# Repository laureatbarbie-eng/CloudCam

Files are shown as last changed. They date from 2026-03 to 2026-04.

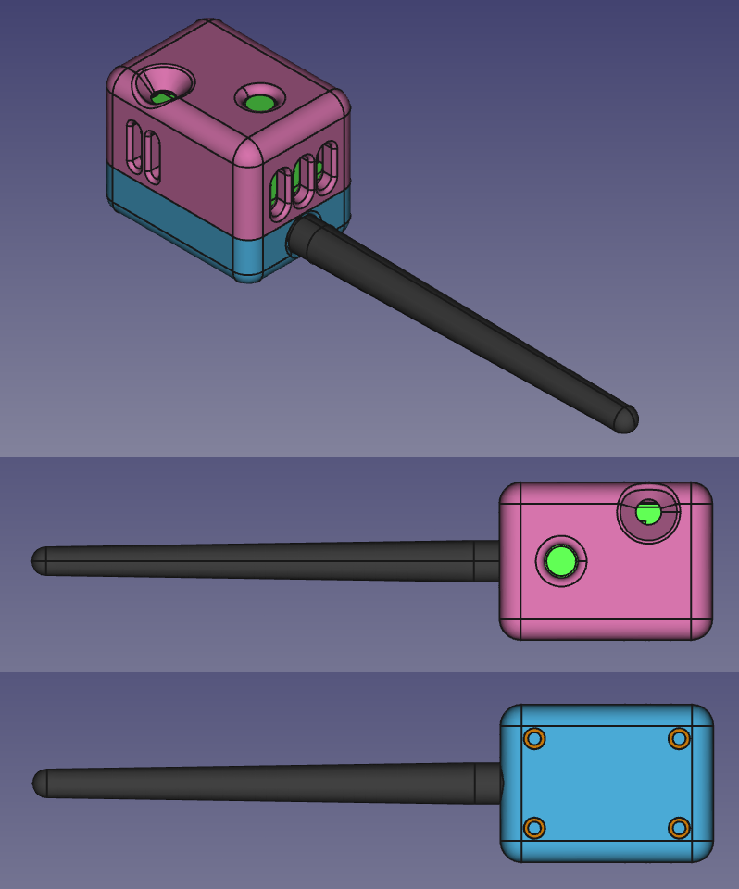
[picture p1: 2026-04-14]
esp-32cam case/cam_multiview_cad.png

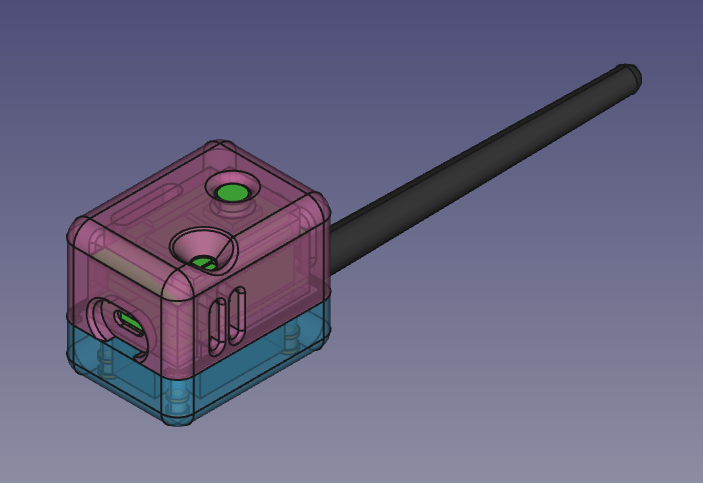
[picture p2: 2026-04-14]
esp-32cam case/cam-transparent-cad.png

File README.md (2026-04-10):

# Проект Скайр (Skyr): Моностатический измеритель ВНГО (CloudCam)

Аппаратно-программный комплекс для пассивного оптического измерения высоты нижней границы облачности (ВНГО), скорости и направления ее движения, а также общего балла облачности. 

Система разработана на основе моностатического метода С.В. Зуева и использует две камеры, расположенные вплотную (на малом базисе), но оснащенные объективами с разными фокусными расстояниями (например, с углами обзора 120° и 160°). За счет разницы в масштабе и использования стереоскопических алгоритмов система вычисляет расстояние до облачного фрагмента, а оптический поток позволяет определить параметры ветра.

---

## 1. Требования к оборудованию

Для сборки комплекса вам потребуются:
*   **Вычислительный модуль:** Raspberry Pi 5 (или 4) с установленной Raspberry Pi OS.
*   **Камеры:** 2× модуля ESP32-CAM (рекомендуются сенсоры OV2640 или OV5640) со сверхширокоугольными линзами (120° — `cam120` и 160° — `cam160`).
*   **Питание:** Стабильный источник 5V (рекомендуется DC-DC преобразователь), общая "земля" (GND).
*   **Дополнительно:** USB-TTL программатор (3.3V) для прошивки ESP32-CAM, калибровочный шаблон (шахматная доска 9x6).
*   **Монтаж:** Жесткая рама для фиксации камер с оптическими осями, направленными строго в зенит, и известным базисным расстоянием (рекомендуется ~0.8–1.0 м).

---

## 2. Структура проекта

Файловая система на Raspberry Pi разделена на директории сервера, обработки и хранения изображений:

*   `/opt/cloudcam/server/` — Сервер-координатор (Flask/Gunicorn). Содержит `app.py`, `config.json`, `requirements.txt`.
*   `/opt/cloudcam/processing/` — Скрипты калибровки и вычисления ВНГО:
    *   `cbh_compute.py` — основной алгоритм расчета ВНГО.
    *   `cbh_gui.py` — веб-интерфейс / панель мониторинга.
    *   `calib/capture_calib_pairs.py` — сбор калибровочных пар.
    *   `calib/calibrate_fisheye_single.py` — расчет внутренних параметров (intrinsics).
    *   `calib/calibrate_fisheye_stereo.py` — расчет внешних параметров (extrinsics).
    *   `calib_out/` — директория для YAML-файлов с результатами калибровки.
*   `/var/lib/cloudcam/` — Хранилище данных:
    *   `cam120/` и `cam160/` — полученные JPEG-изображения и JSON-метаданные.
    *   `stereo_calib/`, `cam120_calib/`, `cam160_calib/` — кадры для калибровки.
    *   `results/` — результаты работы (`vnogo.csv`, `vnogo.jsonl`).

---

## 3. Инструкция по развертыванию (Deployment Guide)

### Шаг 1. Настройка Raspberry Pi (Точка доступа и сервер)
1. **Поднимите Wi-Fi AP** (CloudCamAP), чтобы ESP32-CAM могли подключаться локально.
2. **Установите системные зависимости:**
   ```bash
   sudo apt update
   sudo apt install -y python3 python3-pip python3-venv
   ```
   *Замечание:* системные пакеты или виртуальные окружения необходимы для обхода ошибки `externally-managed-environment` (PEP 668).
3. **Разверните структуру сервера:**
   ```bash
   sudo mkdir -p /opt/cloudcam/server
   sudo chown -R pi:pi /opt/cloudcam
   cd /opt/cloudcam/server
   python3 -m venv venv
   ./venv/bin/pip install -r requirements.txt
   ```
   Подготовьте каталоги для данных:
   ```bash
   sudo mkdir -p /var/lib/cloudcam/cam120 /var/lib/cloudcam/cam160 /var/lib/cloudcam/results
   sudo chown -R pi:pi /var/lib/cloudcam
   ```
  
4. **Настройте автозапуск сервера (systemd):**
   Скопируйте `cloudcam.service` в `/etc/systemd/system/`, затем выполните:
   ```bash
   sudo systemctl daemon-reload
   sudo systemctl enable cloudcam.service
   sudo systemctl restart cloudcam.service
   ```
   Проверьте статус: `curl http://192.168.4.1:8000/health` (должен вернуть JSON `status: ok`).

### Шаг 2. Прошивка ESP32-CAM
1. Подключите ESP32-CAM к USB-TTL: `5V ↔ 5V`, `GND ↔ GND`, `U0T ↔ RX`, `U0R ↔ TX`. Для входа в режим прошивки замкните `IO0` на `GND` и нажмите RESET.
2. Откройте проект в PlatformIO (`esp32cam_vngo`). Убедитесь, что в `platformio.ini` включен параметр `BOARD_HAS_PSRAM`.
3. В исходном коде (`main.cpp`) настройте параметры подключения:
   * `WIFI_SSID = "CloudCamAP"`
   * Для камеры 120° установите `CAM_ID = "cam120"`, для камеры 160° — `CAM_ID = "cam160"`.
   * Убедитесь, что `CAPTURE_PERIOD_SEC = 600` (строго 10 минут) и настроен переход в Deep Sleep.
4. Прошейте каждую камеру поочередно. После загрузки уберите перемычку `IO0` и перезагрузите модули.

---

## 4. Калибровка камер (Критический этап)
Камеры со сверхширокоугольными объективами имеют сильную бочкообразную дисторсию (fisheye-искажения). Без жесткой калибровки метод работать не будет.

1. **Подготовка:** Распечатайте PDF с шахматной доской (9х6 внутренних углов), жестко закрепите мишень на плоской поверхности.
2. **Сбор данных:** Разместите доску перед камерами на разных расстояниях и под разными ракурсами. Система должна отработать 20–40 циклов, захватывая доску.
3. **Сохранение пар:** Запустите скрипт сортировки калибровочных пар:
   ```bash
   python3 /opt/cloudcam/processing/calib/capture_calib_pairs.py --n 30
   ```
   *Скрипт отберет синхронные кадры в папки `stereo_calib`, `cam120_calib`, `cam160_calib`.*
4. **Расчет внутренних параметров (K, D):**
   ```bash
   python3 /opt/cloudcam/processing/calib/calibrate_fisheye_single.py # Для cam120
   python3 /opt/cloudcam/processing/calib/calibrate_fisheye_single.py # Для cam160
   ```
   *Результаты сохранятся в `calib_out/cam120_fisheye.yml` и `cam160_fisheye.yml`.*
5. **Расчет внешних параметров (R, T):**
   ```bash
   python3 /opt/cloudcam/processing/calib/calibrate_fisheye_stereo.py
   ```
   *Результат: `calib_out/stereo_fisheye.yml`.*

---

## 5. Расчет параметров и запуск мониторинга

### Определение ВНГО
После успешной калибровки система готова к измерению ВНГО. Алгоритм `cbh_compute.py` использует модель `cv.fisheye.stereoRectify` для выпрямления кадров, находит сопряженные точки алгоритмом ORB, фильтрует ложные соответствия с помощью RANSAC и выполняет триангуляцию. ВНГО рассчитывается как нижний перцентиль глубин 3D-точек в центральной зоне кадра.

Для ручного запуска расчета выполните:
```bash
python3 /opt/cloudcam/processing/cbh_compute.py
```
*Данные сохранятся в `vnogo.csv` и `vnogo.jsonl`.*

### Веб-панель (GUI)
Комплекс оснащен современной асинхронной веб-панелью на базе фреймворка NiceGUI (запускается через `cbh_gui.py`). Интерфейс предоставляет возможности для мониторинга вычисленных значений ВНГО, просмотра логов телеметрии и графиков, а также удаленного обновления прошивок (OTA).

### Определение скорости и направления ветра
Движение облачности рассчитывается оптическим потоком. Рекомендуется метод FFT Phase Correlation из репозитория Waggle (кросс-корреляция в частотной области). Полученный в пикселях сдвиг конвертируется в м/с на основе данных о ВНГО, физическом размере пикселя сенсора и фокусном расстоянии объектива.

---

## 6. Решение типовых проблем

* **Зависания ESP32 (WDT / Capture FAILED / EV-EOF-OVF):**
  Убедитесь, что используется неблокирующее чтение HTTP с тайм-аутами. Снизьте тактовую частоту сенсора (`xclk_freq_hz`) до 10 МГц, установите `frame_size` на `QVGA` или `VGA` и `fb_count=1` или 2.
* **Проблемы с Long-poll координацией на сервере:**
  Если сервер зависает в ожидании снимков, проверьте работоспособность `gunicorn` (`/etc/systemd/system/cloudcam.service`).
* **Неточность расчета триангуляции:**
  Стереопараллакс при сверхшироких линзах (120/160°) и малом базисе очень мал. Обязательна точная калибровка `fisheye`. При необходимости увеличьте базис до ~0.8–1 м и убедитесь, что оптические оси направлены строго в зенит.
* **Работа в ночное время:**
  Модули OV2640/OV5640 испытывают трудности с распознаванием облачных текстур ночью без подсветки луны. Этот режим имеет ограничения и требует отдельной конфигурации экспозиции или использования инфракрасной камеры.

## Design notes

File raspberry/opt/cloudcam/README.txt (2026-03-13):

README.txt — CloudCam VNOGO (2×ESP32-CAM OV2640: 120° + 160°) — zenith

0) Цель
Система каждые 10 минут делает синхронную пару снимков неба (cam120 + cam160),
сохраняет изображения и метаданные на Raspberry Pi и рассчитывает ВНГО (высоту нижней границы облачности)
в метрах с записью в CSV/JSONL и (опционально) выводом в отдельном окне.

1) Состав системы
1.1) Железо
- Raspberry Pi 5 (или 4) с Raspberry Pi OS.
- 2× ESP32-CAM AI-Thinker (OV2640) + линзы:
  - камера A: 120° (cam120)
  - камера B: 160° (cam160)
- Питание: стабильные 5V (желательно DC-DC), общий GND.
- 2× USB-TTL (3.3V) или один — прошивать по очереди.
- Жёсткая рама. Для высокой точности желательно обеспечить базис ~0.8–1.0 м
  между центрами объективов и строгое направление в зенит.

1.2) ПО (узлы)
- ESP32-CAM: прошивки main_cam120.cpp и main_cam160.cpp
- Raspberry Pi:
  - /opt/cloudcam/server/app.py — сервер/координатор (hello/waitcmd/upload/waitack)
  - /opt/cloudcam/processing/* — калибровка и вычисление ВНГО

2) Структура каталогов (RPi)
- /opt/cloudcam/server/
  - app.py
  - config.json
  - requirements.txt
- /opt/cloudcam/processing/
  - config.json
  - cbh_compute.py
  - cbh_gui.py (опционально)
  - calib/
    - capture_calib_pairs.py
    - calibrate_fisheye_single.py
    - calibrate_fisheye_stereo.py
  - calib_out/   (сюда пишутся результаты калибровки)
- /var/lib/cloudcam/
  - cam120/  (jpg + json метаданные)
  - cam160/
  - stereo_calib/ (пары шахматки для стерео-калибровки)
  - cam120_calib/ (кадры шахматки для одиночной калибровки)
  - cam160_calib/
  - results/
    - vnogo.csv
    - vnogo.jsonl

3) Подключение ESP32-CAM к USB-TTL
- 5V ↔ 5V
- GND ↔ GND
- U0T(ESP) ↔ RX(USB-TTL)
- U0R(ESP) ↔ TX(USB-TTL)
Прошивка:
- IO0 -> GND, затем RESET.
После прошивки:
- IO0 убрать (не на GND), RESET.

4) Прошивка ESP32-CAM (PlatformIO)
4.1) platformio.ini
- включить PSRAM (BOARD_HAS_PSRAM).
4.2) main_cam120.cpp / main_cam160.cpp
- CAM_ID должен быть cam120 и cam160 соответственно.
- CAPTURE_PERIOD_SEC = 600 (строго 10 минут).
- Реализовано CAPTURE_AT по server_ms и local_ms (выравнивание моментов).
- Upload отправляет multipart:
  - поле meta (JSON)
  - поле file (jpeg)
Проверка в Serial:
- должны быть логи [TIMING] wifi_connect, hello, waitcmd, capture, upload, waitack, затем sleep.

5) Настройка Raspberry Pi (сервер)
5.1) Установка зависимостей
sudo apt update
sudo apt install -y python3 python3-venv

5.2) Развёртывание сервера
sudo mkdir -p /opt/cloudcam/server
sudo chown -R pi:pi /opt/cloudcam
cd /opt/cloudcam/server
python3 -m venv venv
./venv/bin/pip install -r requirements.txt

5.3) Каталоги данных
sudo mkdir -p /var/lib/cloudcam/cam120 /var/lib/cloudcam/cam160 /var/lib/cloudcam/results
sudo chown -R pi:pi /var/lib/cloudcam

5.4) systemd
sudo cp /opt/cloudcam/server/cloudcam.service /etc/systemd/system/
sudo systemctl daemon-reload
sudo systemctl enable cloudcam.service
sudo systemctl restart cloudcam.service
Проверка:
curl http://192.168.4.1:8000/health

6) Контроль получения кадров
- Подключите обе камеры к Wi-Fi AP.
- Дождитесь 1–2 циклов.
- В /var/lib/cloudcam/cam120 и /var/lib/cloudcam/cam160 должны появляться:
  - <cycle>_<UTCts>.jpg
  - <cycle>_<UTCts>.json
В json смотрите:
- rssi, capture_ms, jpeg_bytes, time_valid, cmd_server_ms, t_capture_ms.

7) Калибровка (обязательная часть для точности)
Важно: у вас линзы 120/160°, это fisheye, нужна fisheye-модель OpenCV.

7.1) Подготовка шахматки
- Распечатайте шахматку 9x6 внутренних углов.
- Точно измерьте размер клетки (например 30 мм).
- Для калибровки делайте кадры так, чтобы шахматка попадала и в центр, и в края кадра.

7.2) Съёмка калибровочных кадров
- Запускаете систему в обычном режиме (каждые 10 минут).
- Перед камерами держите шахматку под разными углами/положениями.
- Соберите 20–40 циклов с шахматкой.

7.3) Выделение последних N пар для калибровки
python3 /opt/cloudcam/processing/calib/capture_calib_pairs.py --n 30
После этого появятся:
- /var/lib/cloudcam/stereo_calib/<cycle>_cam120.jpg и <cycle>_cam160.jpg
- /var/lib/cloudcam/cam120_calib/<cycle>.jpg
- /var/lib/cloudcam/cam160_calib/<cycle>.jpg

7.4) Одиночная калибровка (intrinsics)
python3 /opt/cloudcam/processing/calib/calibrate_fisheye_single.py  (CAM_ID=cam120)
python3 /opt/cloudcam/processing/calib/calibrate_fisheye_single.py  (CAM_ID=cam160)
Результаты:
- /opt/cloudcam/processing/calib_out/cam120_fisheye.yml
- /opt/cloudcam/processing/calib_out/cam160_fisheye.yml

7.5) Стерео калибровка (extrinsics + rectification)
python3 /opt/cloudcam/processing/calib/calibrate_fisheye_stereo.py
Результат:
- /opt/cloudcam/processing/calib_out/stereo_fisheye.yml

8) Расчёт ВНГО
8.1) Конфиг
Отредактируйте /opt/cloudcam/processing/config.json:
- storage_dir = /var/lib/cloudcam
- cam_left = cam120
- cam_right = cam160
- calib_dir = /opt/cloudcam/processing/calib_out
- min_height_m / max_height_m

8.2) Запуск расчёта вручную
python3 /opt/cloudcam/processing/cbh_compute.py
Выход:
- /var/lib/cloudcam/results/vnogo.csv
- /var/lib/cloudcam/results/vnogo.jsonl

8.3) Окно вывода (опционально)
python3 /opt/cloudcam/processing/cbh_gui.py

9) Как интерпретируется высота (зенит)
- Камеры смотрят строго в зенит.
- После rectification и триангуляции высота ВНГО оценивается по глубине вдоль оптической оси (Z),
поскольку оптическая ось направлена вверх.
- Итог ВНГО берётся как нижний перцентиль по высоте среди валидных 3D-точек в центральном ROI.

10) Надёжность и типовые проблемы
10.1) WDT/зависания на ESP32
- Используйте неблокирующее чтение HTTP с таймаутами (readLine + общий timeout).
- Смотрите тайминги [TIMING] для выявления “где пропали секунды”.

10.2) Capture FAILED / нестабильный захват
- Уменьшить frame_size (VGA -> QVGA).
- Снизить xclk_freq_hz 20MHz -> 10MHz.
- fb_count=1 и grab_mode=WHEN_EMPTY (если нужно).

10.3) Плохой Wi‑Fi (долгий upload)
- Смотрите rssi в meta.json.
- Увеличьте окно UPLOAD_WAIT_SEC на сервере (waitack), если нужно.
- Убедитесь, что WiFi.setSleep(false) включён (иначе power-save может ломать long-poll).

11) Режим “ночь”
- На OV2640 ночью текстура облаков часто недостаточна без подсветки/светового фона.
- Для ночи в перспективе потребуется отдельное исследование: выдержки, шум/компрессия, критерии достоверности.

12) Что считается “успешной установкой”
- Каждые 10 минут появляются пары jpg/json для обеих камер.
- Раз в 10 минут или по запуску cbh_compute.py добавляется строка в vnogo.csv.
- GUI показывает последнее значение VNOGO.

Конец README

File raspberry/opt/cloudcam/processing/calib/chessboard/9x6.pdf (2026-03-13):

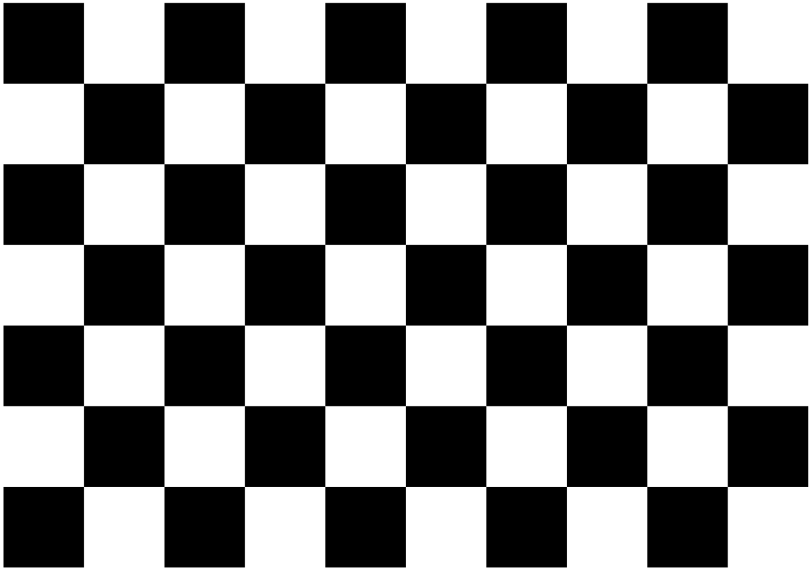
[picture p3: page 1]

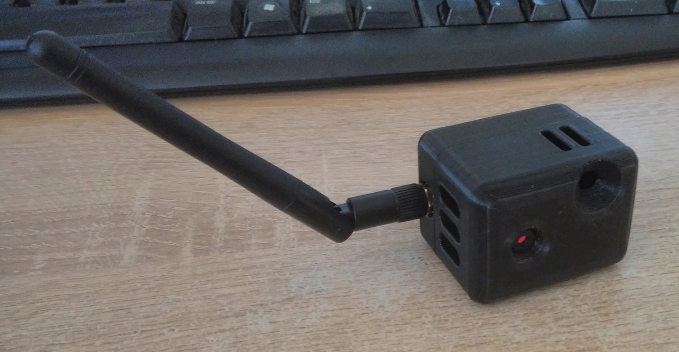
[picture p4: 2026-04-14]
esp-32cam case/cam-front.jpg

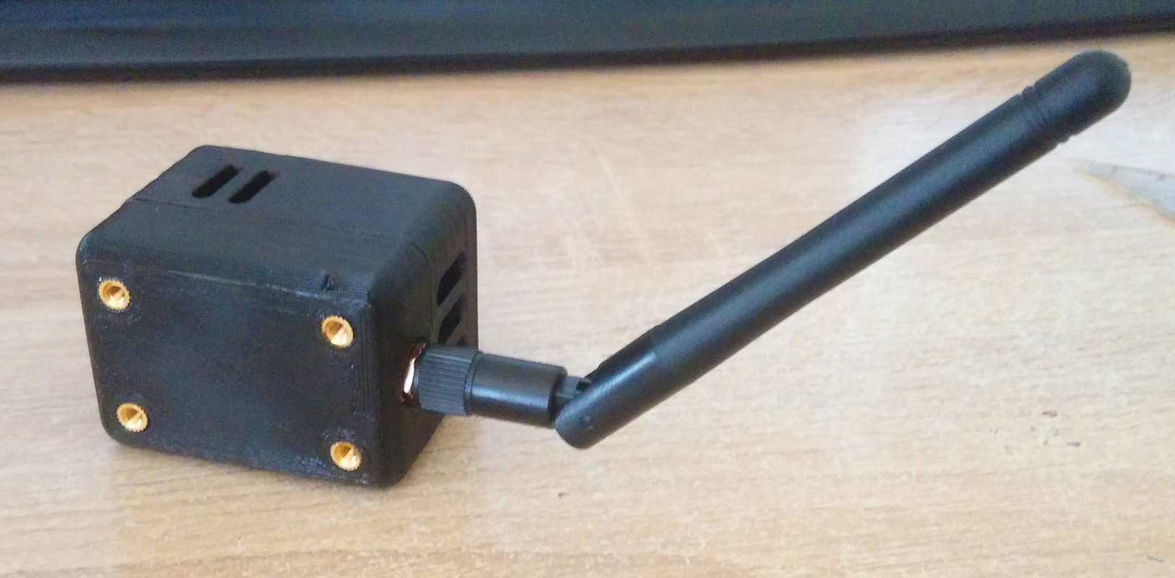
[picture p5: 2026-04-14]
esp-32cam case/cam-back.jpg

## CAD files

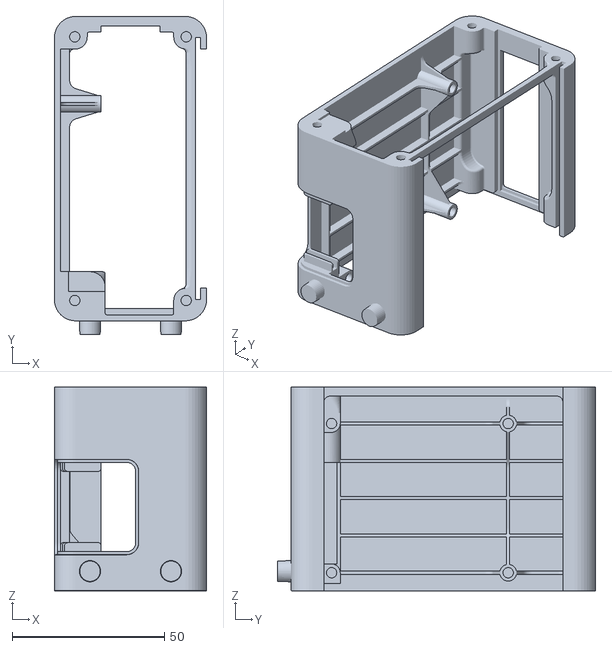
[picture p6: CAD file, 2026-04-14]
raspberry case/Main-body.STL
50.0 x 104.5 x 67.0

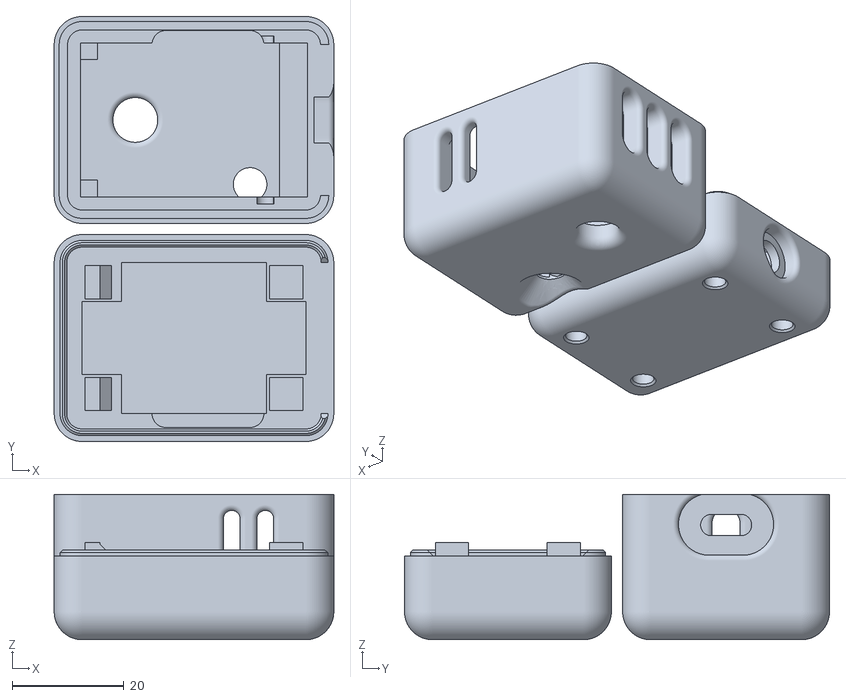
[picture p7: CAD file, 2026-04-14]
esp-32cam case/esp32-cam-shell-combined.stl
50.0 x 76.0 x 26.0

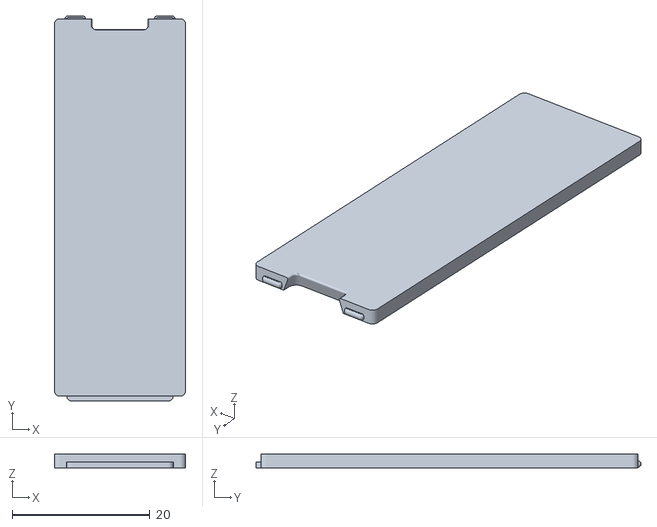
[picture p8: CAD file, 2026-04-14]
raspberry case/Top-IO-cover.STL
19.1 x 56.0 x 2.00

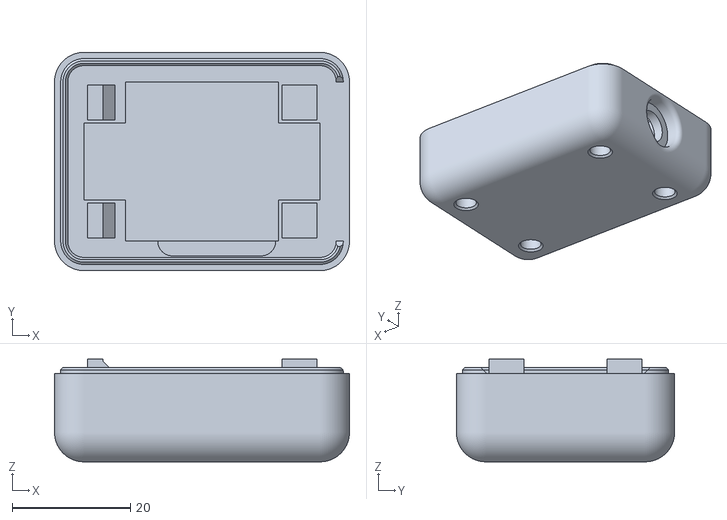
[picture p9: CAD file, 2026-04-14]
esp-32cam case/esp32-cam-shell-back.stl
50.0 x 37.0 x 17.4

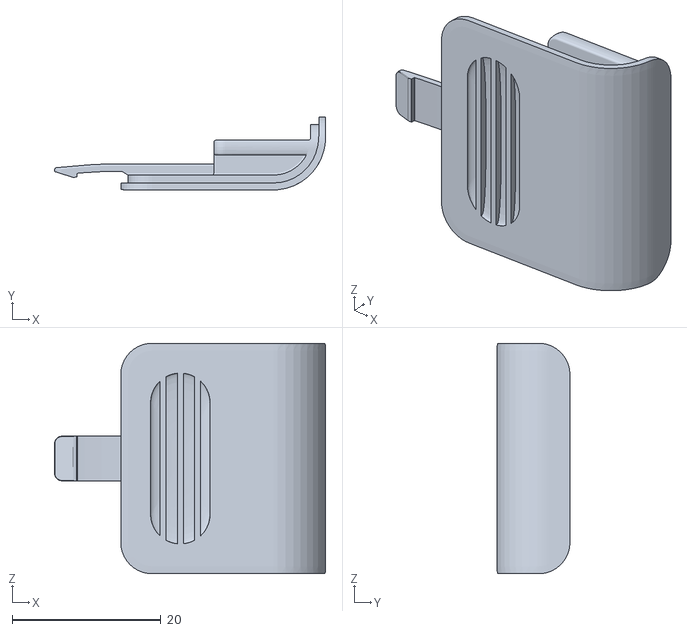
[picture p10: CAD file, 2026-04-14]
raspberry case/Bottom-hatch.STL
36.4 x 9.80 x 30.9

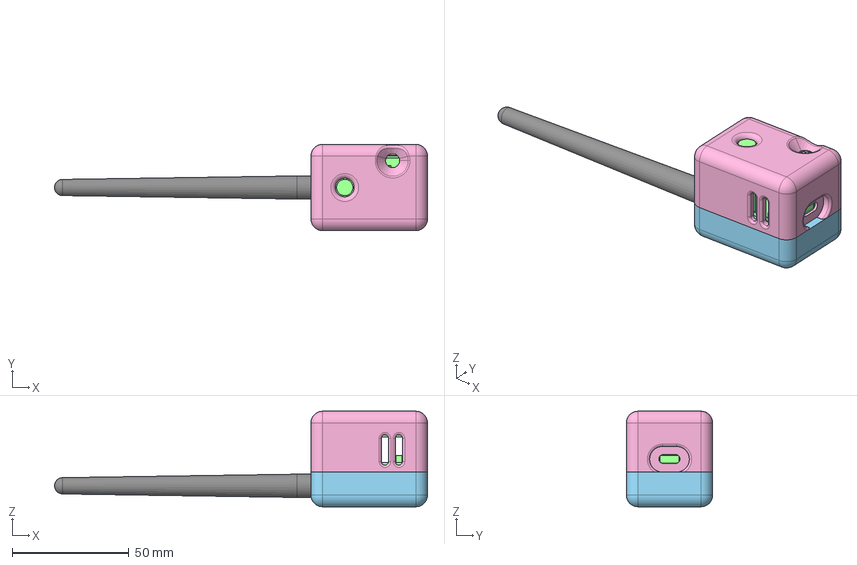
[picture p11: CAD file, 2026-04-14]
esp-32cam case/esp32-cam-shell.FCStd
160.0 x 37.0 x 41.0 mm
pcb-main
sma-female
m3-insert-5x5-001
m3-insert-5x5-002
m3-insert-5x5-003
m3-insert-5x5-004
shell-front
shell-back

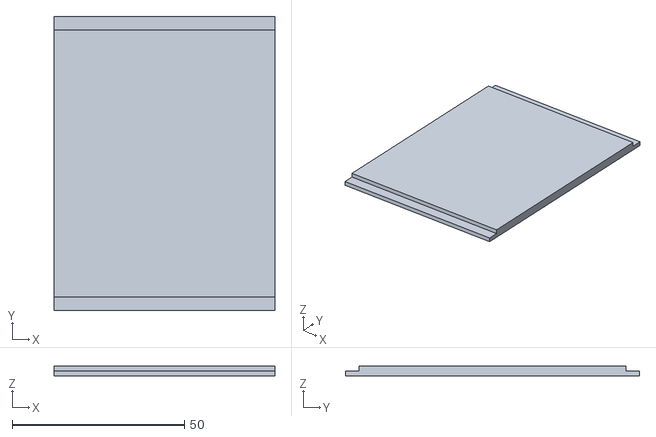
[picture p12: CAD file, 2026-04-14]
raspberry case/Side-panel.STL
64.2 x 85.4 x 3.00

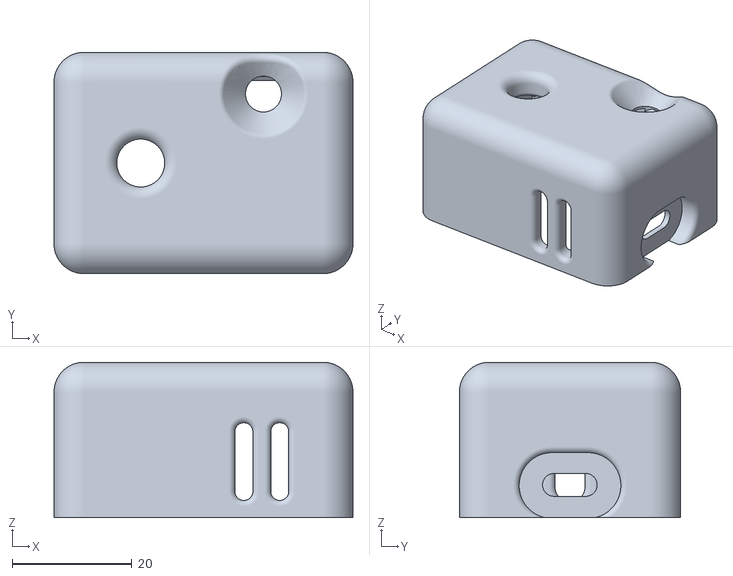
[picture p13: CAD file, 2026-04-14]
esp-32cam case/esp32-cam-shell-front.stl
50.0 x 37.0 x 26.0

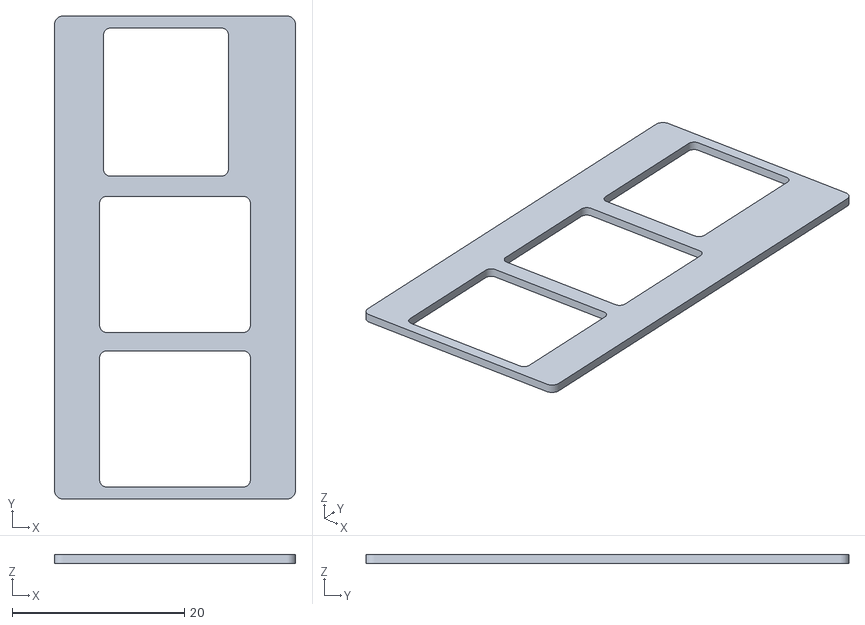
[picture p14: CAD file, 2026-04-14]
raspberry case/Top-IO.STL
28.0 x 56.1 x 1.00

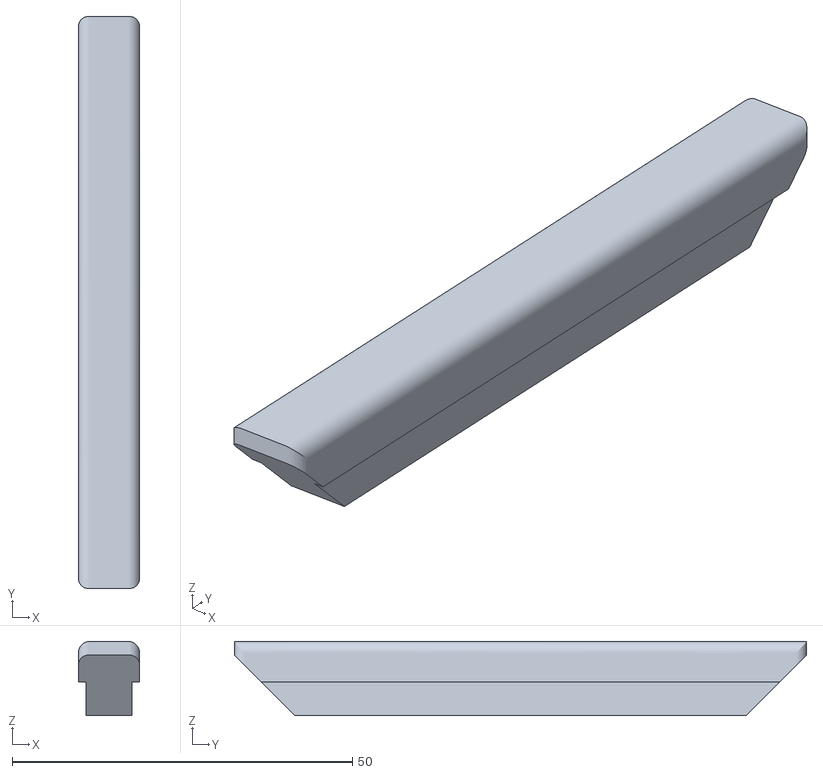
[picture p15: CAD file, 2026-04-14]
raspberry case/Front-bar.STL
9.00 x 84.0 x 10.9

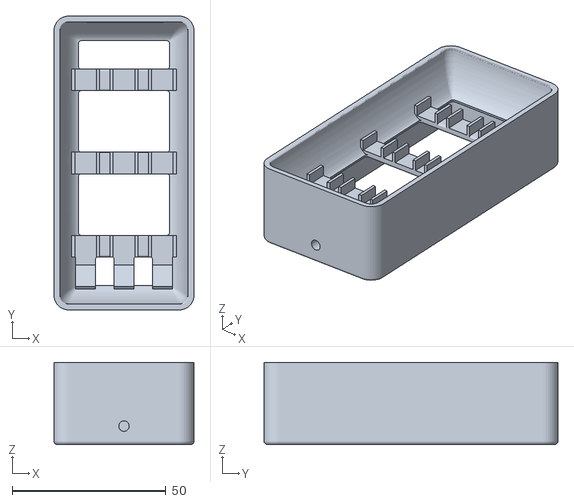
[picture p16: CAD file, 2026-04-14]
raspberry case/Front-inner-frame.STL
45.5 x 95.5 x 26.7

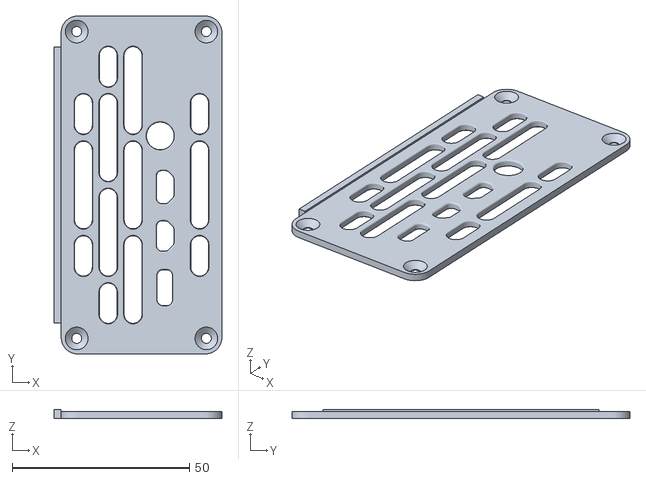
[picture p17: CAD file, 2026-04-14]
raspberry case/Rear-panel_Pi4+5.STL
47.4 x 95.4 x 2.50

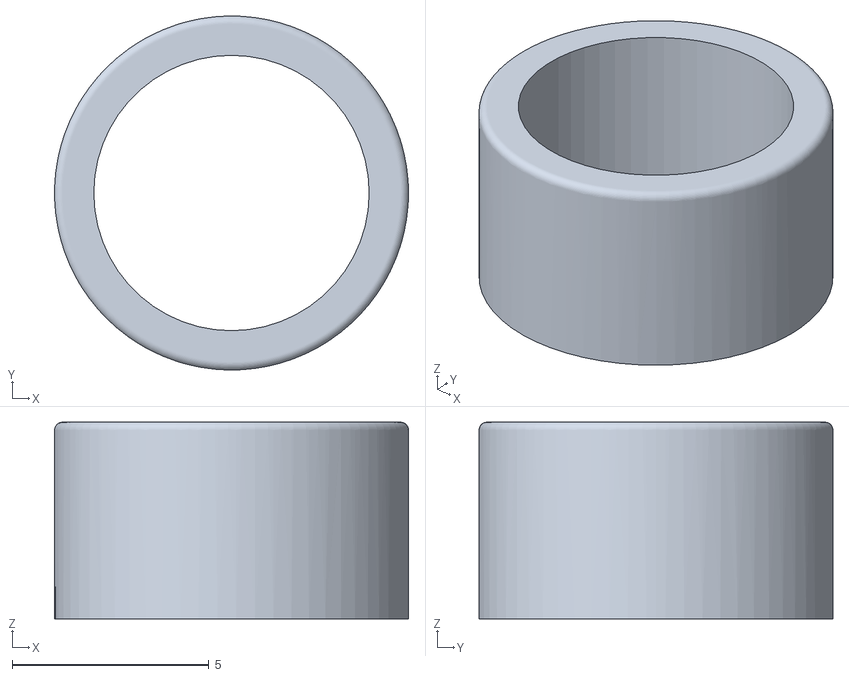
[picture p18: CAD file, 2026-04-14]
raspberry case/Foot-ring.STL
9.00 x 9.00 x 5.00

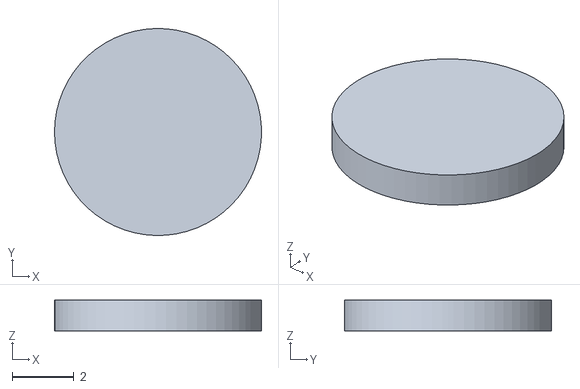
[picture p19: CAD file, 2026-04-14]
raspberry case/Foot-rubber-pad.STL
6.69 x 6.68 x 1.00

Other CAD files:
raspberry case/Rear-panel_vents-only.STL
raspberry case/Front.STL
raspberry case/Rear-panel_Pi5-only.STL

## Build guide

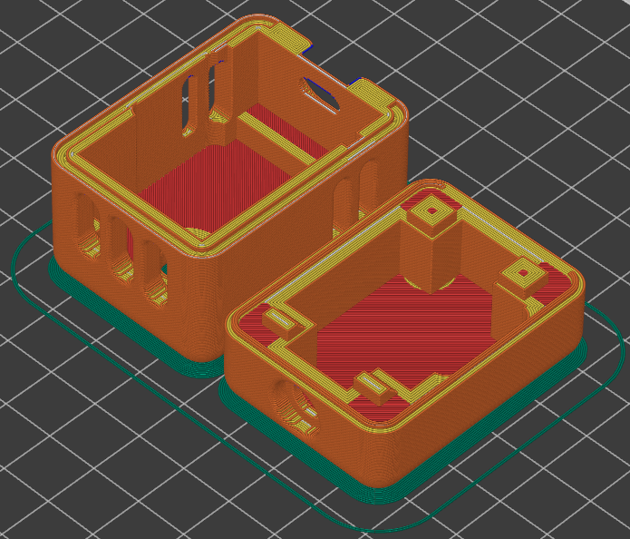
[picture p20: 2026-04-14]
esp-32cam case/cam-printbed-layout.png

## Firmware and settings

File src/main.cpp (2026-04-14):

#include <Arduino.h>
#include "esp_camera.h"
#include <WiFi.h>
#include <time.h>
#include <esp_task_wdt.h>
#include <HTTPClient.h> // ДОБАВЛЕНО для OTA
#include <HTTPUpdate.h> // ДОБАВЛЕНО для OTA

// ------------------- CONFIG -------------------
static const char* WIFI_SSID = "CloudCamAP";
static const char* WIFI_PASS = "cloudcam2024";
static const char* SERVER_HOST = "192.168.4.1";
static const uint16_t SERVER_PORT = 8000;
static const char* CAM_ID = "cam120";

// ДОБАВЛЕНО: API Токен для авторизации на сервере
static const char* API_TOKEN = "SecretCloudToken123";

static const uint32_t CAPTURE_PERIOD_SEC = 600;
static const uint32_t FAIL_SLEEP_SEC = 120;
static const uint32_t CHUNK_SIZE = 8192;
static const uint8_t UPLOAD_MAX_RETRIES = 3;
static const uint8_t CHUNK_MAX_RETRIES = 5;

static const uint32_t WIFI_TIMEOUT_MS = 15000;
static const uint32_t CMD_TOTAL_WAIT_MS = 50000;
static const uint32_t ACK_TOTAL_WAIT_MS = 60000;

// SNTP: увеличенный таймаут + retry (но необязательный для синхронизации)
static const uint32_t SNTP_TIMEOUT_MS = 15000;
static const uint8_t SNTP_MAX_RETRIES = 3;

static const uint32_t HTTP_SOCK_TIMEOUT_MS = 5000;
static const uint32_t CHUNK_SOCK_TIMEOUT_MS = 8000;

static const bool WIFI_DISABLE_SLEEP = true;
static const bool WIFI_MAX_TXPOWER = false;

static const size_t TCP_WRITE_BLOCK = 1460;

#define LED_FLASH_GPIO GPIO_NUM_4
#define STATUS_LED_GPIO GPIO_NUM_33

// Глобальный буфер для HTTP запросов (избегаем кучи String в цикле)
static char httpBodyBuffer[256];

// ------------------- CRC32 -------------------
static uint32_t crc32_table[256];
static bool crc32_table_computed = false;

static void make_crc32_table() {
  if (crc32_table_computed) return;
  for (uint32_t n = 0; n < 256; n++) {
    uint32_t c = n;
    for (int k = 0; k < 8; k++) {
      c = (c & 1) ? (0xedb88320UL ^ (c >> 1)) : (c >> 1);
    }
    crc32_table[n] = c;
  }
  crc32_table_computed = true;
}

static uint32_t crc32(const uint8_t *buf, size_t len) {
  make_crc32_table();
  uint32_t c = 0xffffffffUL;
  for (size_t n = 0; n < len; n++) {
    c = crc32_table[(c ^ buf[n]) & 0xff] ^ (c >> 8);
  }
  return c ^ 0xffffffffUL;
}

// ------------------- Helpers -------------------
static uint32_t ms() { return millis(); }

static void goToSleep(uint32_t seconds) {
  Serial.printf("[SLEEP] %u sec\n", seconds);
  esp_sleep_enable_timer_wakeup((uint64_t)seconds * 1000000ULL);
  esp_deep_sleep_start();
}

static void blinkStatus(uint8_t times, uint16_t onms, uint16_t offms) {
  for (uint8_t i = 0; i < times; i++) {
    digitalWrite(STATUS_LED_GPIO, LOW);
    delay(onms);
    digitalWrite(STATUS_LED_GPIO, HIGH);
    delay(offms);
  }
}

// ДОБАВЛЕНО: Генерация заголовка авторизации
static String getAuthHeader() {
  return String("Authorization: Bearer ") + API_TOKEN + "\r\n";
}

static bool readLine(WiFiClient &c, String &line, uint32_t timeoutMs) {
  line = "";
  uint32_t t0 = ms();
  while (ms() - t0 < timeoutMs) {
    while (c.available()) {
      char ch = (char)c.read();
      if (ch == '\r') continue;
      if (ch == '\n') return true;
      line += ch;
    }
    if (!c.connected()) return line.length() > 0;
    delay(1);
  }
  return false;
}

struct HttpResp {
  int status = -1;
  String body;
};

static bool httpRequestRaw(const String &req, HttpResp &out, uint32_t totalTimeoutMs) {
  out = HttpResp();

  WiFiClient client;
  if (!client.connect(SERVER_HOST, SERVER_PORT)) {
    Serial.println("[ERR] HTTP: Failed to connect");
    return false;
  }
  client.setTimeout(HTTP_SOCK_TIMEOUT_MS);
  client.setNoDelay(true);

  client.print(req);
  uint32_t t0 = ms();

  String statusLine;
  if (!readLine(client, statusLine, 3000)) { 
    client.stop(); 
    return false; 
  }

  int sp = statusLine.indexOf(' ');
  if (sp < 0) { client.stop(); return false; }
  int sp2 = statusLine.indexOf(' ', sp + 1);
  String codeStr = (sp2 > sp) ? statusLine.substring(sp + 1, sp2) : statusLine.substring(sp + 1);
  out.status = codeStr.toInt();

  int contentLen = -1;
  while (true) {
    String h;
    if (!readLine(client, h, 3000)) { client.stop(); return false; }
    if (h.length() == 0) break;
    String hl = h; hl.toLowerCase();
    if (hl.startsWith("content-length:")) contentLen = hl.substring(15).toInt();
    if (ms() - t0 > totalTimeoutMs) { client.stop(); return false; }
  }

  String body;
  if (contentLen >= 0) body.reserve(contentLen + 8);

  if (contentLen >= 0) {
    while ((int)body.length() < contentLen && (ms() - t0 < totalTimeoutMs)) {
      while (client.available() && (int)body.length() < contentLen)
        body += (char)client.read();
      if (!client.connected() && !client.available()) break;
      delay(1);
    }
  } else {
    while (ms() - t0 < totalTimeoutMs) {
      while (client.available()) body += (char)client.read();
      if (!client.connected() && !client.available()) break;
      delay(1);
    }
  }

  client.stop();
  body.trim();
  out.body = body;
  return true;
}

static bool jsonFindInt(const String &json, const char *key, int &out) {
  String pat = String("\"") + key + "\":";
  int idx = json.indexOf(pat);
  if (idx < 0) return false;
  int colon = json.indexOf(':', idx);
  if (colon < 0) return false;
  colon++;
  while (colon < (int)json.length() && (json[colon] == ' ' || json[colon] == '"')) colon++;
  String num = "";
  while (colon < (int)json.length() && (isdigit(json[colon]) || json[colon] == '-'))
    num += json[colon++];
  if (num.length() == 0) return false;
  out = num.toInt();
  return true;
}

static bool jsonFindString(const String &json, const char *key, String &out) {
  String pat = String("\"") + key + "\":\"";
  int idx = json.indexOf(pat);
  if (idx < 0) return false;
  idx += pat.length();
  int end = json.indexOf('"', idx);
  if (end < 0) return false;
  out = json.substring(idx, end);
  return true;
}

static bool jsonFindBool(const String &json, const char *key, bool &out) {
  String pat = String("\"") + key + "\":";
  int idx = json.indexOf(pat);
  if (idx < 0) return false;
  int colon = json.indexOf(':', idx);
  if (colon < 0) return false;
  colon++;
  while (colon < (int)json.length() && json[colon] == ' ') colon++;
  if (json.substring(colon).startsWith("true")) { out = true; return true; }
  if (json.substring(colon).startsWith("false")) { out = false; return true; }
  return false;
}

static void wifiTuneAfterConnect() {
  if (WIFI_DISABLE_SLEEP) WiFi.setSleep(false);
  if (WIFI_MAX_TXPOWER) WiFi.setTxPower(WIFI_POWER_19_5dBm);
}

static bool connectWiFi(uint32_t timeoutMs) {
  WiFi.mode(WIFI_STA);
  WiFi.begin(WIFI_SSID, WIFI_PASS);
  uint32_t t0 = ms();
  while (WiFi.status() != WL_CONNECTED && (ms() - t0 < timeoutMs)) {
    delay(50);
    esp_task_wdt_reset();
  }
  if (WiFi.status() != WL_CONNECTED) {
    Serial.println("[ERR] WiFi connection failed");
    return false;
  }
  wifiTuneAfterConnect();
  Serial.printf("[WIFI] Connected IP=%s RSSI=%d\n", WiFi.localIP().toString().c_str(), WiFi.RSSI());
  return true;
}

// SNTP с retry логикой (необязательный результат)
static bool syncTimeSNTP() {
  configTime(0, 0, SERVER_HOST);
  
  for (uint8_t attempt = 1; attempt <= SNTP_MAX_RETRIES; attempt++) {
    uint32_t t0 = ms();
    struct tm ti;
    
    while (ms() - t0 < SNTP_TIMEOUT_MS) {
      esp_task_wdt_reset();
      if (getLocalTime(&ti, 200)) {
        Serial.printf("[SNTP] Synced on attempt %d\n", attempt);
        return true;
      }
      delay(50);
    }
    
    if (attempt < SNTP_MAX_RETRIES) {
      Serial.printf("[SNTP] Attempt %d failed, retrying...\n", attempt);
      delay(1000);
    }
  }
  
  Serial.println("[SNTP] All attempts failed, continuing without time sync");
  return false;
}

// ИСПРАВЛЕНО: переименовано в OV2640 (так как настройки именно для неё)
// ------------------- Camera Init OV2640 -------------------
static void startCameraOV2640() {
  camera_config_t config;
  config.ledc_channel = LEDC_CHANNEL_0;
  config.ledc_timer = LEDC_TIMER_0;
  
  config.pin_d0 = 5;
  config.pin_d1 = 18;
  config.pin_d2 = 19;
  config.pin_d3 = 21;
  config.pin_d4 = 36;
  config.pin_d5 = 39;
  config.pin_d6 = 34;
  config.pin_d7 = 35;
  config.pin_xclk = 0;
  config.pin_pclk = 22;
  config.pin_vsync = 25;
  config.pin_href = 23;
  config.pin_sccb_sda = 26;
  config.pin_sccb_scl = 27;
  config.pin_pwdn = 32;
  config.pin_reset = -1;

  config.xclk_freq_hz = 10000000;
  config.pixel_format = PIXFORMAT_JPEG;

  if (!psramFound()) {
    Serial.println("[ERR] PSRAM NOT FOUND - HALTING");
    while (true) delay(1000);
  }

  // Оптимальные настройки для OV2640 на ESP32-CAM
  config.frame_size = FRAMESIZE_UXGA;
  config.jpeg_quality = 10;
  config.fb_count = 2;
  config.fb_location = CAMERA_FB_IN_PSRAM;
  config.grab_mode = CAMERA_GRAB_LATEST;

  esp_err_t err = esp_camera_init(&config);
  if (err != ESP_OK) {
    Serial.printf("[ERR] Camera init failed: 0x%x\n", err);
    while (true) delay(1000);
  }

  sensor_t *s = esp_camera_sensor_get();
  if (s) {
    s->set_brightness(s, 0);
    s->set_contrast(s, 0);
    s->set_saturation(s, 0);
    s->set_whitebal(s, 1);
    s->set_awb_gain(s, 1);
    s->set_exposure_ctrl(s, 1);
    s->set_gain_ctrl(s, 1);
    s->set_gainceiling(s, (gainceiling_t)2);
    s->set_lenc(s, 1);
    s->set_raw_gma(s, 1);
    s->set_bpc(s, 1);
    s->set_wpc(s, 1);
    s->set_hmirror(s, 0);
    s->set_vflip(s, 0);
  }
  
  Serial.println("[OK] OV2640 initialized");
  Serial.printf("[INFO] Resolution: UXGA (1600x1200), Quality: 10, Buffers: 2, XCLK: 10MHz\n");
}

// ------------------- API Calls -------------------
static bool postHello(int &cycleIdOut, int &delayMsOut) {
  String payload = String("{\"deviceid\":\"") + CAM_ID + "\",\"local_ms\":" + String(ms()) + "}";
  String req =
      String("POST /hello HTTP/1.1\r\n") +
      "Host: " + SERVER_HOST + ":" + String(SERVER_PORT) + "\r\n" +
      getAuthHeader() +
      "Connection: close\r\n" +
      "Content-Type: application/json\r\n" +
      "Content-Length: " + String(payload.length()) + "\r\n\r\n" +
      payload;

  HttpResp r;
  if (!httpRequestRaw(req, r, 7000)) return false;
  if (r.status != 200) return false;

  int cid = -1, delay_ms = -1;
  if (!jsonFindInt(r.body, "cycle_id", cid)) return false;
  if (!jsonFindInt(r.body, "capture_delay_ms", delay_ms)) return false;
  cycleIdOut = cid;
  delayMsOut = delay_ms;
  return true;
}

static bool waitCmd(int cycleId, int &captureMsOut) {
  uint32_t t0 = ms();
  while (ms() - t0 < CMD_TOTAL_WAIT_MS) {
    esp_task_wdt_reset();
    String path = String("/waitcmd?deviceid=") + CAM_ID + "&cycle_id=" + String(cycleId) + "&local_ms=" + String(ms());
    String req =
        String("GET ") + path + " HTTP/1.1\r\n" +
        "Host: " + SERVER_HOST + ":" + String(SERVER_PORT) + "\r\n" +
        getAuthHeader() +
        "Connection: close\r\n\r\n";

    HttpResp r;
    if (!httpRequestRaw(req, r, 35000)) { delay(100); continue; }
    if (r.status != 200) { delay(100); continue; }

    if (r.body.indexOf("\"type\":\"CAPTURE_AT\"") >= 0) {
      int delay_ms = -1;
      if (!jsonFindInt(r.body, "capture_delay_ms", delay_ms)) return false;
      captureMsOut = delay_ms;
      return true;
    }
    delay(100);
  }
  return false;
}

static bool waitAck(int cycleId, bool &sleepOut) {
  uint32_t t0 = ms();
  while (ms() - t0 < ACK_TOTAL_WAIT_MS) {
    esp_task_wdt_reset();
    String path = String("/waitack?deviceid=") + CAM_ID + "&cycle_id=" + String(cycleId);
    String req =
        String("GET ") + path + " HTTP/1.1\r\n" +
        "Host: " + SERVER_HOST + ":" + String(SERVER_PORT) + "\r\n" +
        getAuthHeader() +
        "Connection: close\r\n\r\n";

    HttpResp r;
    if (!httpRequestRaw(req, r, 35000)) { delay(100); continue; }
    if (r.status != 200) { delay(100); continue; }

    bool s = false;
    if (!jsonFindBool(r.body, "sleep", s)) { delay(100); continue; }
    sleepOut = s;
    return true;
  }
  return false;
}

// ------------------- Resume Upload -------------------
static bool initUpload(int cycleId, size_t jpegSize, uint32_t jpegCrc, String &transferIdOut, int &resumeFromChunk) {
  int chunkCount = (jpegSize + CHUNK_SIZE - 1) / CHUNK_SIZE;

  String payload = String("{") +
    "\"cam_id\":\"" + CAM_ID + "\"," +
    "\"cycle_id\":" + String(cycleId) + "," +
    "\"jpeg_size\":" + String(jpegSize) + "," +
    "\"chunk_size\":" + String(CHUNK_SIZE) + "," +
    "\"chunk_count\":" + String(chunkCount) + "," +
    "\"jpeg_crc32\":\"" + String(jpegCrc, HEX) + "\"," +
    "\"rssi\":" + String(WiFi.RSSI()) +
    "}";

  String req =
      String("POST /upload/init HTTP/1.1\r\n") +
      "Host: " + SERVER_HOST + ":" + String(SERVER_PORT) + "\r\n" +
      getAuthHeader() +
      "Connection: close\r\n" +
      "Content-Type: application/json\r\n" +
      "Content-Length: " + String(payload.length()) + "\r\n\r\n" +
      payload;

  HttpResp r;
  if (!httpRequestRaw(req, r, 12000)) return false;
  if (r.status != 200) return false;

  String tid;
  int resume = 0;
  if (!jsonFindString(r.body, "transfer_id", tid)) return false;
  jsonFindInt(r.body, "resume_from_chunk", resume);

  transferIdOut = tid;
  resumeFromChunk = resume;
  return true;
}

static bool uploadChunk(const String &transferId, int chunkIndex, const uint8_t *data, size_t len) {
  uint32_t chunkCrc = crc32(data, len);

  WiFiClient client;
  if (!client.connect(SERVER_HOST, SERVER_PORT)) {
    Serial.printf("[ERR] Chunk %d: Failed to connect\n", chunkIndex);
    return false;
  }

  client.setTimeout(CHUNK_SOCK_TIMEOUT_MS);
  client.setNoDelay(true);

  String headers =
      String("POST /upload/chunk HTTP/1.1\r\n") +
      "Host: " + SERVER_HOST + ":" + String(SERVER_PORT) + "\r\n" +
      getAuthHeader() +
      "Connection: close\r\n" +
      "X-Transfer-ID: " + transferId + "\r\n" +
      "X-Chunk-Index: " + String(chunkIndex) + "\r\n" +
      "X-Chunk-CRC32: " + String(chunkCrc, HEX) + "\r\n" +
      "Content-Type: application/octet-stream\r\n" +
      "Content-Length: " + String(len) + "\r\n\r\n";

  client.print(headers);

  size_t written = 0;
  size_t remaining = len;
  const uint8_t *ptr = data;

  while (remaining > 0) {
    size_t blk = (remaining > TCP_WRITE_BLOCK) ? TCP_WRITE_BLOCK : remaining;
    size_t w = client.write(ptr, blk);
    if (w == 0) {
      Serial.printf("[ERR] Chunk %d: Write stalled at %u/%u bytes\n", chunkIndex, written, len);
      break;
    }
    written += w;
    ptr += w;
    remaining -= w;

    delay(2);
  }

  if (written != len) {
    client.stop();
    return false;
  }

  String statusLine;
  if (!readLine(client, statusLine, 5000)) {
    client.stop();
    return false;
  }

  statusLine.trim();
  client.stop();

  return (statusLine.startsWith("HTTP/1.1 200") || statusLine.startsWith("HTTP/1.0 200"));
}

static bool finalizeUpload(const String &transferId) {
  String payload = String("{\"transfer_id\":\"") + transferId + "\"}";
  String req =
      String("POST /upload/finalize HTTP/1.1\r\n") +
      "Host: " + SERVER_HOST + ":" + String(SERVER_PORT) + "\r\n" +
      getAuthHeader() +
      "Connection: close\r\n" +
      "Content-Type: application/json\r\n" +
      "Content-Length: " + String(payload.length()) + "\r\n\r\n" +
      payload;

  HttpResp r;
  if (!httpRequestRaw(req, r, 12000)) return false;
  return (r.status == 200);
}

static bool uploadImageResumable(camera_fb_t *fb, int cycleId) {
  if (!fb || !fb->buf || fb->len == 0) {
    Serial.println("[ERR] Invalid frame buffer");
    return false;
  }

  // Проверка доступности WiFi перед загрузкой
  if (WiFi.status() != WL_CONNECTED) {
    Serial.println("[ERR] WiFi disconnected before upload");
    return false;
  }

  uint32_t jpegCrc = crc32(fb->buf, fb->len);
  int chunkCount = (fb->len + CHUNK_SIZE - 1) / CHUNK_SIZE;

  Serial.printf("[UPLOAD] JPEG size=%u CRC=0x%08X chunks=%d\n", fb->len, jpegCrc, chunkCount);

  String transferId;
  int resumeFromChunk = 0;

  for (uint8_t attempt = 1; attempt <= UPLOAD_MAX_RETRIES; attempt++) {
    if (initUpload(cycleId, fb->len, jpegCrc, transferId, resumeFromChunk)) {
      Serial.printf("[UPLOAD] Init OK: transfer_id=%s resume_from=%d\n", transferId.c_str(), resumeFromChunk);
      break;
    }
    // Проверка WiFi после каждой попытки
    if (WiFi.status() != WL_CONNECTED) {
      Serial.println("[ERR] WiFi lost during upload init");
      return false;
    }
    if (attempt == UPLOAD_MAX_RETRIES) return false;
    delay(500 * attempt);
  }

  uint32_t uploadStart = ms();
  for (int i = resumeFromChunk; i < chunkCount; i++) {
    esp_task_wdt_reset();

    // Проверка WiFi перед каждым чанком
    if (WiFi.status() != WL_CONNECTED) {
      Serial.printf("[ERR] WiFi lost at chunk %d\n", i);
      return false;
    }

    size_t offset = (size_t)i * CHUNK_SIZE;
    size_t chunkLen = (offset + CHUNK_SIZE <= fb->len) ? CHUNK_SIZE : (fb->len - offset);

    bool chunkOk = false;
    for (uint8_t retry = 1; retry <= CHUNK_MAX_RETRIES; retry++) {
      if (uploadChunk(transferId, i, &fb->buf[offset], chunkLen)) {
        chunkOk = true;
        break;
      }
      Serial.printf("[WARN] Chunk %d retry %d\n", i, retry);
      delay(100 * retry);
    }

    if (!chunkOk) {
      Serial.printf("[ERR] Chunk %d failed after %d retries\n", i, CHUNK_MAX_RETRIES);
      return false;
    }

    if ((i % 10) == 0 || i == chunkCount - 1) {
      Serial.printf("[PROGRESS] %d/%d chunks (%.1f%%)\n", i + 1, chunkCount, ((i + 1) * 100.0) / chunkCount);
    }
  }

  uint32_t uploadMs = ms() - uploadStart;
  float rate = (fb->len * 1000.0f) / (uploadMs * 1024.0f);
  Serial.printf("[UPLOAD] Complete in %u ms (%.1f KB/s)\n", uploadMs, rate);

  for (uint8_t attempt = 1; attempt <= UPLOAD_MAX_RETRIES; attempt++) {
    if (finalizeUpload(transferId)) {
      Serial.println("[UPLOAD] Finalized OK");
      return true;
    }
    // Проверка WiFi перед каждой попыткой финализации
    if (WiFi.status() != WL_CONNECTED) {
      Serial.println("[ERR] WiFi lost during finalize");
      return false;
    }
    delay(500 * attempt);
  }

  Serial.println("[ERR] Upload finalize failed after all retries");
  return false;
}

// ------------------- Memory Diagnostics -------------------
static void printHeapInfo(const char* location) {
  Serial.printf("[MEM] %s: Free heap=%u Min free=%u PSRAM free=%u\n", 
                location, 
                ESP.getFreeHeap(), 
                ESP.getMinFreeHeap(),
                ESP.getFreePsram());
}

// ------------------- OTA Update -------------------
static void checkForOTA() {
  WiFiClient client;
  // Обращаемся к веб-интерфейсу на порт 8080 за файлом прошивки
  String ota_url = String("http://") + SERVER_HOST + ":8080/ota/" + CAM_ID + ".bin";
  Serial.printf("[OTA] Checking for update at %s\n", ota_url.c_str());

  client.setTimeout(15000); // Даем больше времени на скачивание бинарника
  
  // Отключаем проверку версии, просто шьем, если файл доступен
  t_httpUpdate_return ret = httpUpdate.update(client, ota_url);

  switch (ret) {
    case HTTP_UPDATE_FAILED:
      // Ошибка 404 (файла нет) - это нормальное поведение, если мы не загрузили прошивку
      Serial.printf("[OTA] No update found or failed (%d): %s\n", httpUpdate.getLastError(), httpUpdate.getLastErrorString().c_str());
      break;
    case HTTP_UPDATE_NO_UPDATES:
      Serial.println("[OTA] No updates");
      break;
    case HTTP_UPDATE_OK:
      Serial.println("[OTA] Success! Rebooting...");
      // После успешной прошивки ESP32 перезагрузится автоматически
      break;
  }
}
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
void loop() {}

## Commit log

2026-03-13 Complete reset and fix of embedded server folder
    [main.cpp]
2026-03-13 Удалил ненужные файлы, адаптирую их под свой репозиторий позже
2026-03-13 Изменил файлы под свой репозитоий
2026-03-23 Fix camera firmware errors and improve reliability
    Key features implemented:
    - Added detailed error logging and diagnostic output for WiFi connection failures
    - Implemented memory heap diagnostics with printHeapInfo function for monitoring RAM usage
    - Enhanced WiFi connection with improved error reporting showing IP address and RSSI
    - Added missing WiFi status checks before upload operations to prevent disconnection issues
    - Improved HTTP client timeout handling and connection validation throughout the code
    - Added TCP write blocking with configurable packet size (1460 bytes) for stable uploads
    - Enhanced camera initialization with proper error handling and detailed configuration
    The change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
    [main.cpp]
2026-03-24 Поправлен приемник распбери и доработана прошивка
2026-03-28 Скрипты калибровки отработаны, добавлен тестовый скрипт на измерение расстояния до шахматной доски
2026-03-28 Добавлена прошивка для калибровки камер по 30 секунд без глубокого сна
2026-03-28 Создал шаблон веб-интерфейса/панели управления системой
2026-03-31 Уточнение
2026-03-31 Обновить требования к оборудованию в README
    Обновлены требования к оборудованию, заменив Raspberry Pi 4B на Raspberry Pi 5 и добавив информацию о камерах ESP-32CAM.
2026-04-01 Реализован сквозной пайплайн: сервер теперь ждет два кадра от 3-й камеры, не закрывая цикл. Скрипт обработки извлекает смещение ($\Delta$ px) методом FFT и конвертирует его в скорость ветра на основе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
2026-04-10 Синхронизирована логика CloudCam под 3-ю камеру cam180 и нестабильный тайминг прихода кадров:
    Принят единый Wi‑Fi профиль для ESP32: Raspberry / 12345678 (без смены текущей прошивки).
    Унифицирован идентификатор 3-й камеры: используем cam180 (вместо смешения с cam180_sky).
    Серверная логика подтверждения цикла обновлена под burst-режим 3-й камеры: для cam180 ожидается 2 кадра на цикл.
    Расчёт cbh_compute.py адаптирован под сц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
2026-04-10 прошивка
2026-04-10 Изменения
2026-04-14 Add raspberry case files
2026-04-14 case rpi
    [Bottom-hatch.STL, Foot-ring.STL, Foot-rubber-pad.STL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]
2026-04-14 помарка
    [Bottom-hatch.STL, Foot-ring.STL, Foot-rubber-pad.STL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]
2026-04-14 esp-32cam case
    [esp32-cam-shell-back.stl, esp32-cam-shell-combined.stl, esp32-cam-shell-front.stl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]
2026-04-14 Реорганизовал структуру проекта, добавил скрипт удаления системы, добавил пакеты и ависимости для системы
2026-04-16 Refactor: remove wheels from repository and update gitignore
2026-04-16 Вернул директории
2026-04-16 Добавил инструкции по каждой камере
